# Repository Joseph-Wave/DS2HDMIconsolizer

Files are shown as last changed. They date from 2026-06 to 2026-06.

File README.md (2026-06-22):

## DS to HDMI converter

Here is an archive project of mine. It takes the raw video signals of the ds and scale up, pixel to pixel to DVI video in 1080p, 720p, etc. using an artix 7 FPGA (Cmod A7), and play both DS and GBA games.

Demotration can be seen at https://youtube.com/shorts/DusmrjSz5Js

Also share the PCB designs and pinout probing done in the ds family systems (LS030.xlsx), for which the DSi XL is electrically compatible and a second PCB and enclosure were desinged. 
The TFP410 TMDS transmitter and logic buffers are not required in most cases.

Some test roms are included. These are particulary coded to indentify the timing of the 5 bit RGB signals without expensive logic analizer, a cheap off-brand usb 8 Channels is enough.

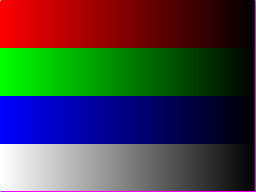
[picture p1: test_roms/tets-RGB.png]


The future plan was to pass the project to a Tang Primer 25K, a cheaper FPGA, or a dedicaded TFP410 Serializer. But never get the time and money to realize them. I share this in case someone had the same vision...
For more on the DVI serialization see: https://github.com/projf/display_controller

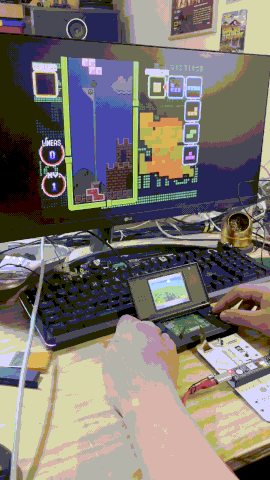
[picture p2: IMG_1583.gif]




The show scale correspont to a x5.

Here is a drawing of the expectated case using a DSi XL screen and a DS Fat motherboard (this model allow easier wiring as both screen data is recived for both displays, only with differing in the clock signal phase)

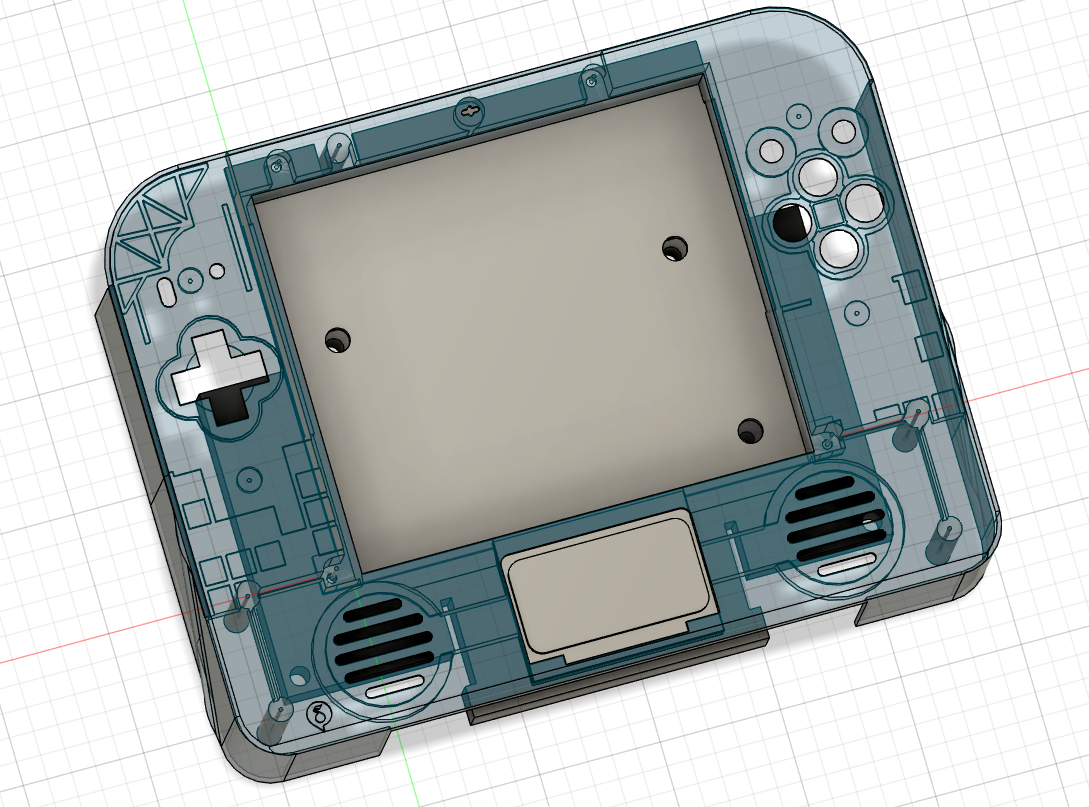
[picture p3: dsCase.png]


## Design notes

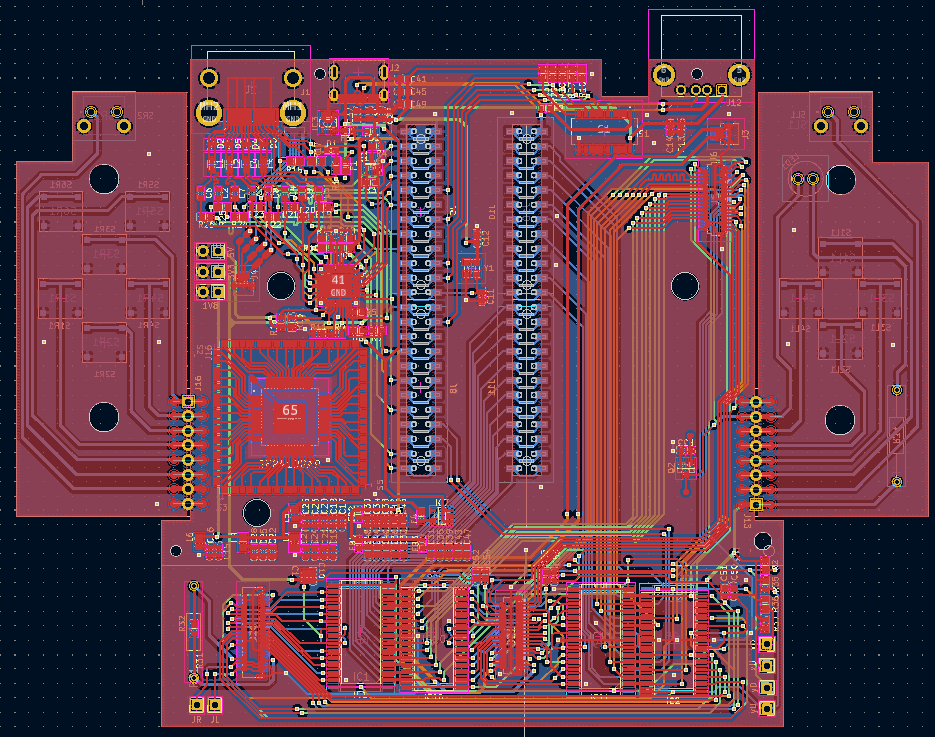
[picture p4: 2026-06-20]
pcb_v2.png

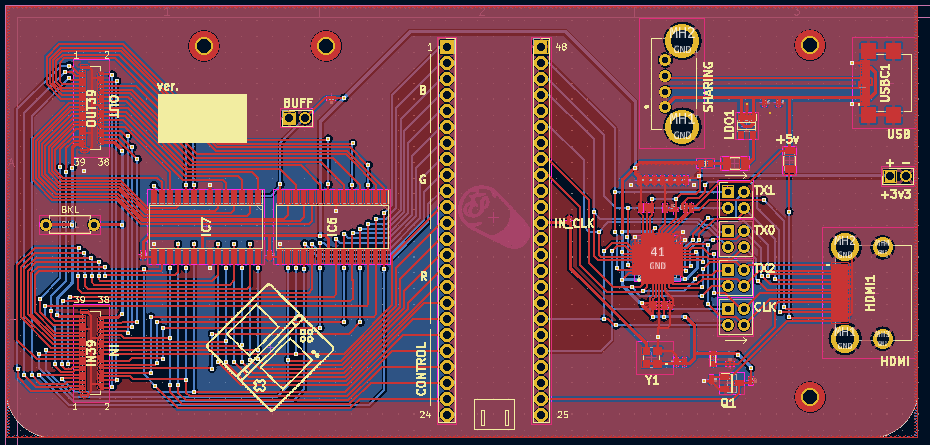
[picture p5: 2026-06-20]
pcb_v1.png

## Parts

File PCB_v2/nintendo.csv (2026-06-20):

Source: | C:\Users\Jojo\Documents\KiCad\nintendo\nintendo_v2b\nintendo\nintendo.kicad_sch
Date: | 9/28/2025 5:50:30 PM
Tool: | Eeschema 7.0.9
Generator: | C:\Program Files\KiCad\7.0\bin\scripting\plugins/bom_csv_grouped_by_value_with_fp.py
Component Count: | 170
Ref | Qnty | Value | Cmp name | Footprint | Description | Vendor | DNP
C1, C10, C16, C18, C20, C21, C23, C24, C25, C26, C27, C28, C34, C35, C36, C37, C38, C39, C40, C41, C42, C43, C44, C45, C46, C47, C48, C49, C50, C51, C52, C53, C54, C55 | 34 | 0.1uF | GRT188C81E475KE13D | Nintendo_Library:CAPC1608X100N | Multilayer Ceramic Capacitors MLCC - SMD/SMT 0603 25Vdc 4.7uF X6S 10%
C2, C3, C4, C5, C6, C7, C8, C9 | 8 | 100nF | GRT188C81E475KE13D | Nintendo_Library:CAPC1608X100N | Multilayer Ceramic Capacitors MLCC - SMD/SMT 0603 25Vdc 4.7uF X6S 10%
C11 | 1 | 0.01uF | GRT188C81E475KE13D | Nintendo_Library:CAPC1608X100N | Multilayer Ceramic Capacitors MLCC - SMD/SMT 0603 25Vdc 4.7uF X6S 10%
C12 | 1 | 15pF | GRT188C81E475KE13D | Nintendo_Library:CAPC1608X100N | Multilayer Ceramic Capacitors MLCC - SMD/SMT 0603 25Vdc 4.7uF X6S 10%
C13, C14, C15, C17, C19, C22, C29, C30, C31, C32, C33 | 11 | 10uF | GRT188C81E475KE13D | Nintendo_Library:CAPC1608X100N | Multilayer Ceramic Capacitors MLCC - SMD/SMT 0603 25Vdc 4.7uF X6S 10%
D1 | 1 | RB520S30T1G | RB520S30T1G | Nintendo_Library:SODFL1608X70N | These are Pb-Free Devices
D2, D3, D4, D5 | 4 | ESD122DMYR | ESD122DMYR | Nintendo_Library:ESD122DMYR | 2-Channel ESD Protection Diode for USB Type-C and HDMI 2.0
F1, F2, F3, F4 | 4 | 0467.250NR | 0467.250NR | Nintendo_Library:FUSC1608X43N | Littelfuse 0.25A FF Non-Resettable Surface Mount Fuses, 32 V
FB1, FB2, FB3, FB4 | 4 | BLM18RK601SN1D | BLM18RK601SN1D | Nintendo_Library:BLM18SP221SN1B | BLM18_N1D Series EMI Suppression Filter 600+/-25% at 100MHz 200mA @85
IC1, IC2, IC4, IC5, IC8, IC9, IC10, IC11 | 8 | SN74ABT5402ADWR | SN74ABT5402ADWR | Nintendo_Library:SOIC127P1030X265-28N | 12-Bit Line/Memory Drivers With 3-State Outputs
IC3 | 1 | BU33TD3WG-TR | BU33TD3WG-TR | Nintendo_Library:SOT95P280X125-5N | ROHM - BU33TD3WG-TR - LDO, FIXED, 3.3V, 0.2A, SSOP-5
IC6 | 1 | TMDS141RHAR | TMDS141RHAR | Nintendo_Library:QFN50P600X600X100-41N-D | HDMI Hider
IC7 | 1 | BU18TD3WG-TR | BU18TD3WG-TR | Nintendo_Library:SOT95P280X125-5N | 1ch 200mA CMOS LDO Regulators: The BU**TD2WNVX / BU**TD3WG series integrates a 200mA output high performance FULL CMOS regulator into an ultra-compact SSON004X1010 package (1.0mm1.0mm0.6mm) & SSOP5 package(2.9mm2.8mm1.15mm). Additional features include a circuit current of only 35A for low power consumption along with superior noise and load response characteristics, making them ideal for use in power supplies for a wide variety of applications, including logic ICs, RF circuits, and camera modules.
IC100 | 1 | TFP410PAP | TFP410PAP | Nintendo_Library:QFP50P1200X1200X120-65N | 165-MHz TMDS DVI transmitter/serializer & Panelbus integrated circuit
J1 | 1 | HDMI-208658-1051 | 208658-1051 | Nintendo_Library:2086581051 | 1.0 HDMI R/A HEADER ASSY (I/M TYPE)
J2 | 1 | USB4215-03-A_REVA | USB4215-03-A_REVA | Nintendo_Library:GCT_USB4215-03-A_REVA
J3, J4, J19 | 3 | 501461-0491 | 501461-0491 | Nintendo_Library:5014610491 | MOLEX - 501461-0491 - CONNECTOR, FPC, 4POS, 1ROW, 0.5MM
J5, J17, J18, J22, J23, J24 | 6 | 87224-1 | 87224-1 | Nintendo_Library:HDRV1W66P0X254_1X1 | 01 MODII HDR SRST UNSHRD .100
J6 | 1 | FH26W-37S-0.3SHW_60_ | FH26W-37S-0.3SHW_60_ | Nintendo_Library:FH26W37S03SHW60 | FFC & FPC Connectors Receptacle 37
J7, J14, J15 | 3 | 67996-100HLF | 67996-100HLF | Nintendo_Library:HDRV2W67P254_2X1_254X483X858P | BergStik<sup>&reg;</sup>, Board to Board connector, Unshrouded vertical header, Through Hole, Double Row, 0 Positions, 2.54 mm (0.100in) Pitch
J8, J9, J10, J11 | 4 | HLE-112-02-F-DV | HLE-112-02-F-DV | Nintendo_Library:HLE-112-02-XXX-DV | 24 Position, Cost Effective Surface Mount Socket, 0.100&quot; Pitch
J12 | 1 | USB1130-15-A | USB1130-15-A | Nintendo_Library:USB113015A | USB Connectors USB A 2.0 Skt RA High Life 15u" T Hole W/Shell Stake T & R
J13, J16 | 2 | ~ | th_separator | Nintendo_Library:th_separator
J20 | 1 | 502598-4593 | 502598-4593 | Nintendo_Library:5025984593 | Molex 502598 Series 0.3mm Pitch 45 Way SMT Female FPC Connector
J21 | 1 | 3-2328724-9 | 3-2328724-9 | Nintendo_Library:323287249 | AMP - TE CONNECTIVITY - 3-2328724-9 - CONNECTOR, FPC, R/A, 39POS, 1ROW, 0.3MM
L1, L2, L3, L4 | 4 | 744230900 | 744230900 | Nintendo_Library:744230900 | SMD Common Mode Noise Suppressor WE-CNSW
L5, L6, L7, L8 | 4 | 10uH | 74479777310 | Nintendo_Library:INDC2012X145N | Wurth WE-PMI Series 10000 nH +/-20% Multilayer SMD Inductor, 0805 Case, SRF: 0.025GHz 650mA dc 500m Rdc
LED1 | 1 | HLMP-K155 | HLMP-K155 | Nintendo_Library:HLMPK150C00A1 | 1.6 V Red LED 3mm Through Hole, Broadcom HLMP-K155
Q1, Q2 | 2 | FDV301N | FDV301N | Nintendo_Library:SOT96P237X111-3N | RDS(ON) = 5 @ VGS= 2.7 V; 25 V, 0.22 A continuous, 0.5 A Peak. ; RDS(ON) = 4 @ VGS= 4.5 VGS(th) < 1.06; Gate-Source Zener for ESD ruggedness. >6kV Human Body Model; Replace multiple NPN digital transistors with one DMOS FET
R1, R6, R7, R13, R15 | 5 | 1.5K | CR0603-FX-1002ELF | Nintendo_Library:RESC1608X55N | SMD 0603 thick film resistor 10K 1% Bourns CR0603-FX Series Thick Film Surface Mount Fixed Resistor 0603 Case 10k +/-1% 0.1W +/-100ppm/C
R2, R4, R8, R9, R10, R11, R12, R14, R16, R27, R28, R29, R30, R35, R36, R37 | 16 | 10K | CR0603-FX-1002ELF | Nintendo_Library:RESC1608X55N | SMD 0603 thick film resistor 10K 1% Bourns CR0603-FX Series Thick Film Surface Mount Fixed Resistor 0603 Case 10k +/-1% 0.1W +/-100ppm/C
R3, R33 | 2 | 100K | CR0603-FX-1002ELF | Nintendo_Library:RESC1608X55N | SMD 0603 thick film resistor 10K 1% Bourns CR0603-FX Series Thick Film Surface Mount Fixed Resistor 0603 Case 10k +/-1% 0.1W +/-100ppm/C
R5 | 1 | 4.6K | CR0603-FX-1002ELF | Nintendo_Library:RESC1608X55N | SMD 0603 thick film resistor 10K 1% Bourns CR0603-FX Series Thick Film Surface Mount Fixed Resistor 0603 Case 10k +/-1% 0.1W +/-100ppm/C
R17, R18, R19, R20, R21, R22, R23, R24, R25, R26 | 10 | 0 | CR0603-FX-1002ELF | Nintendo_Library:RESC1608X55N | SMD 0603 thick film resistor 10K 1% Bourns CR0603-FX Series Thick Film Surface Mount Fixed Resistor 0603 Case 10k +/-1% 0.1W +/-100ppm/C
R31, R34 | 2 | 330 | MFR-25FRF52-10K | Nintendo_Library:RESAD1590W60L630D240 | Metal Film Resistors - Through Hole 10 kOhms 250 mW 1% 100 PPM / C
R32 | 1 | 330 | CR0603-FX-1002ELF | Nintendo_Library:RESC1608X55N | SMD 0603 thick film resistor 10K 1% Bourns CR0603-FX Series Thick Film Surface Mount Fixed Resistor 0603 Case 10k +/-1% 0.1W +/-100ppm/C
S1 | 1 | A6H-8102-PM | A6H-8102-PM | Nintendo_Library:A6H8102PM | DIP Switches / SIP Switches REFLOW TERMINAL DIP
S1L1 | 1 | SKRRAAE010 | SKRRAAE010 | Nintendo_Library:SKRR | Tactile Switches 7.5x7.0x0.6mm 100gf
S1R1 | 1 | SKRRAAE010 | SKRRAAE010 | Nintendo_Library:SKRR | Tactile Switches 7.5x7.0x0.6mm 100gf
S2, S3, S4, S5 | 4 | ~ | Easy_Solder | Nintendo_Library:Easy_Solder
S2L1 | 1 | SKRRAAE010 | SKRRAAE010 | Nintendo_Library:SKRR | Tactile Switches 7.5x7.0x0.6mm 100gf
S2R1 | 1 | SKRRAAE010 | SKRRAAE010 | Nintendo_Library:SKRR | Tactile Switches 7.5x7.0x0.6mm 100gf
S3L1 | 1 | SKRRAAE010 | SKRRAAE010 | Nintendo_Library:SKRR | Tactile Switches 7.5x7.0x0.6mm 100gf
S3R1 | 1 | SKRRAAE010 | SKRRAAE010 | Nintendo_Library:SKRR | Tactile Switches 7.5x7.0x0.6mm 100gf
S4L1 | 1 | SKRRAAE010 | SKRRAAE010 | Nintendo_Library:SKRR | Tactile Switches 7.5x7.0x0.6mm 100gf
S4R1 | 1 | SKRRAAE010 | SKRRAAE010 | Nintendo_Library:SKRR | Tactile Switches 7.5x7.0x0.6mm 100gf
S5R1 | 1 | SKRRAAE010 | SKRRAAE010 | Nintendo_Library:SKRR | Tactile Switches 7.5x7.0x0.6mm 100gf
S6R1 | 1 | SKRRAAE010 | SKRRAAE010 | Nintendo_Library:SKRR | Tactile Switches 7.5x7.0x0.6mm 100gf
SL1 | 1 | 1-1825027-2 | 1-1825027-2 | 118250272 | Switch Tactile OFF (ON) SPST Round Button PC Pins 0.05A 24VDC 2.55N Thru-Hole Loose
SR2 | 1 | 1-1825027-2 | 1-1825027-2 | 118250272 | Switch Tactile OFF (ON) SPST Round Button PC Pins 0.05A 24VDC 2.55N Thru-Hole Loose
Y1 | 1 | DSC1001CE5-148.5000T | DSC1001CE5-148.5000T | Nintendo_Library:DSC1001CE5-148.5000T | 1.8V-3.3V Low-Power Precision CMOS Oscillators

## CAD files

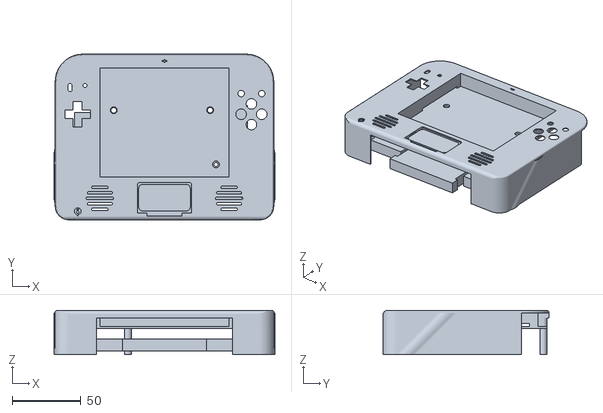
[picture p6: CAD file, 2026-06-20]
dsCase.stl
160.6 x 120.4 x 32.0

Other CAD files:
dsCase.f3d

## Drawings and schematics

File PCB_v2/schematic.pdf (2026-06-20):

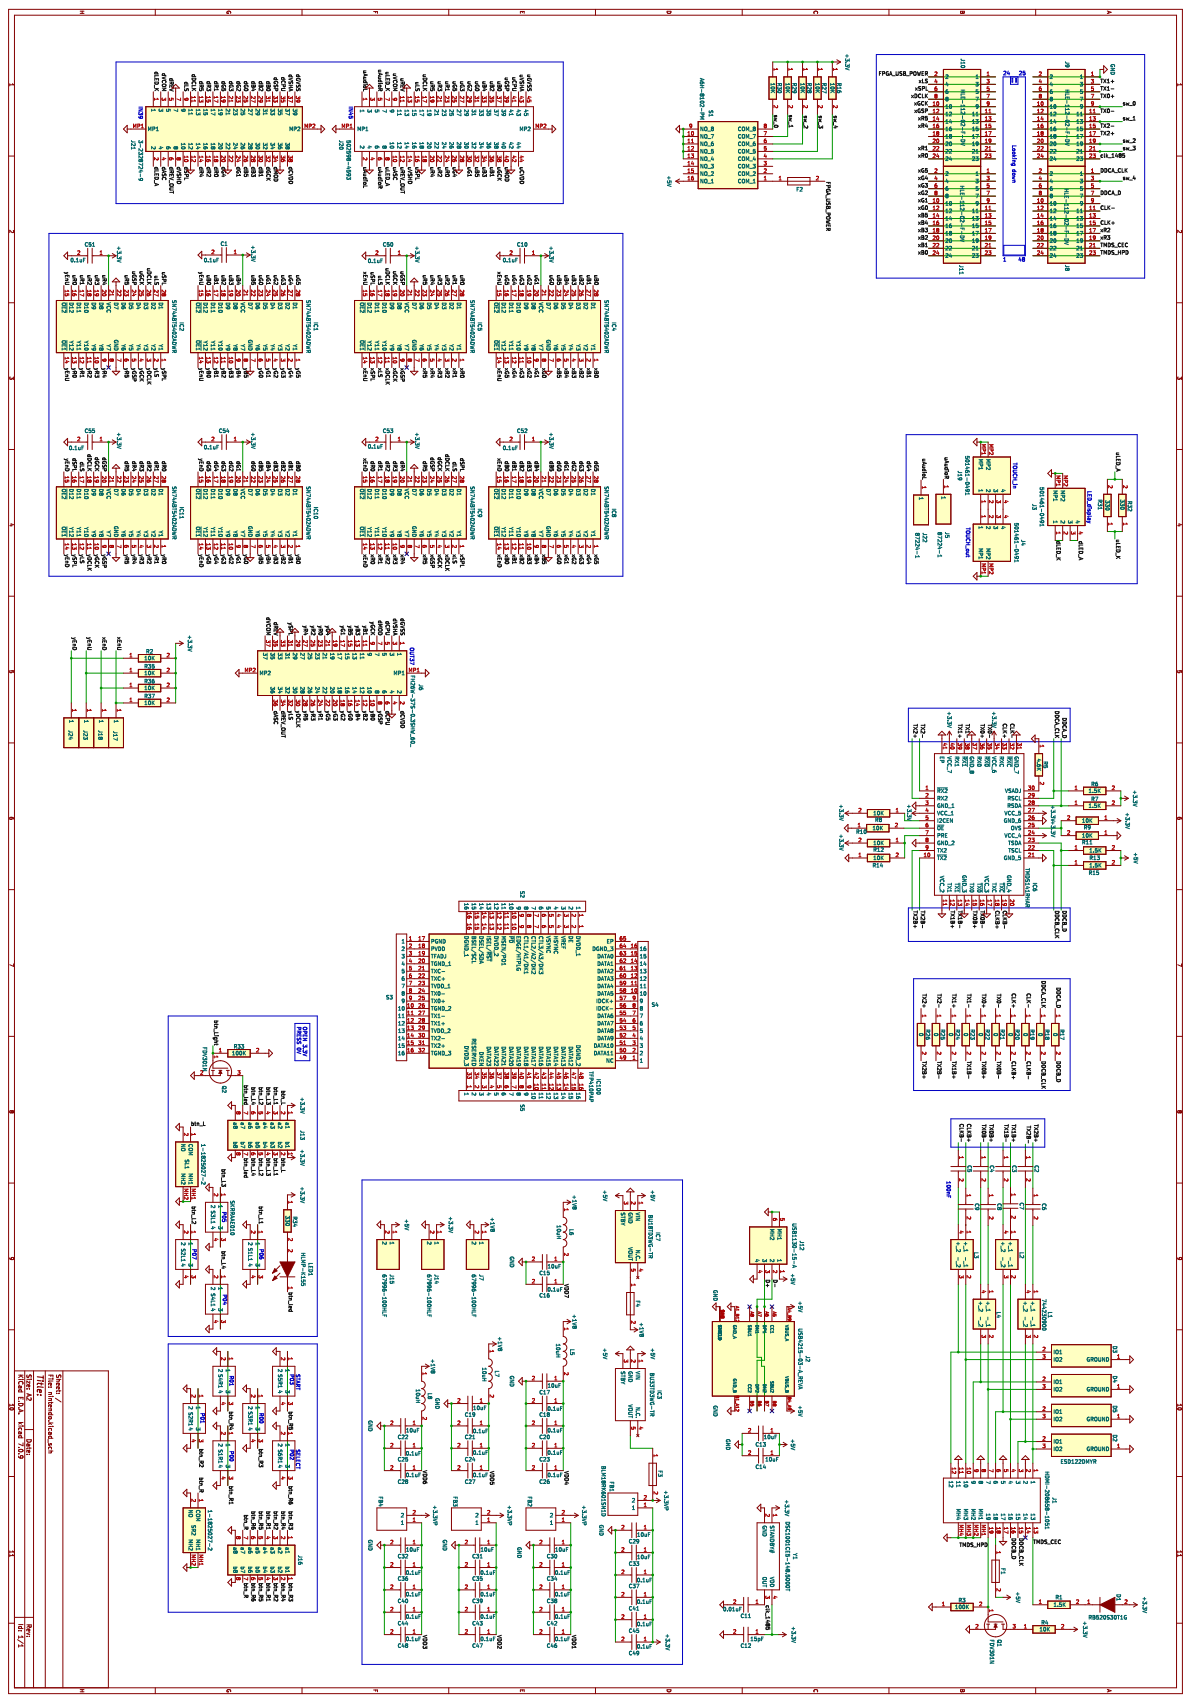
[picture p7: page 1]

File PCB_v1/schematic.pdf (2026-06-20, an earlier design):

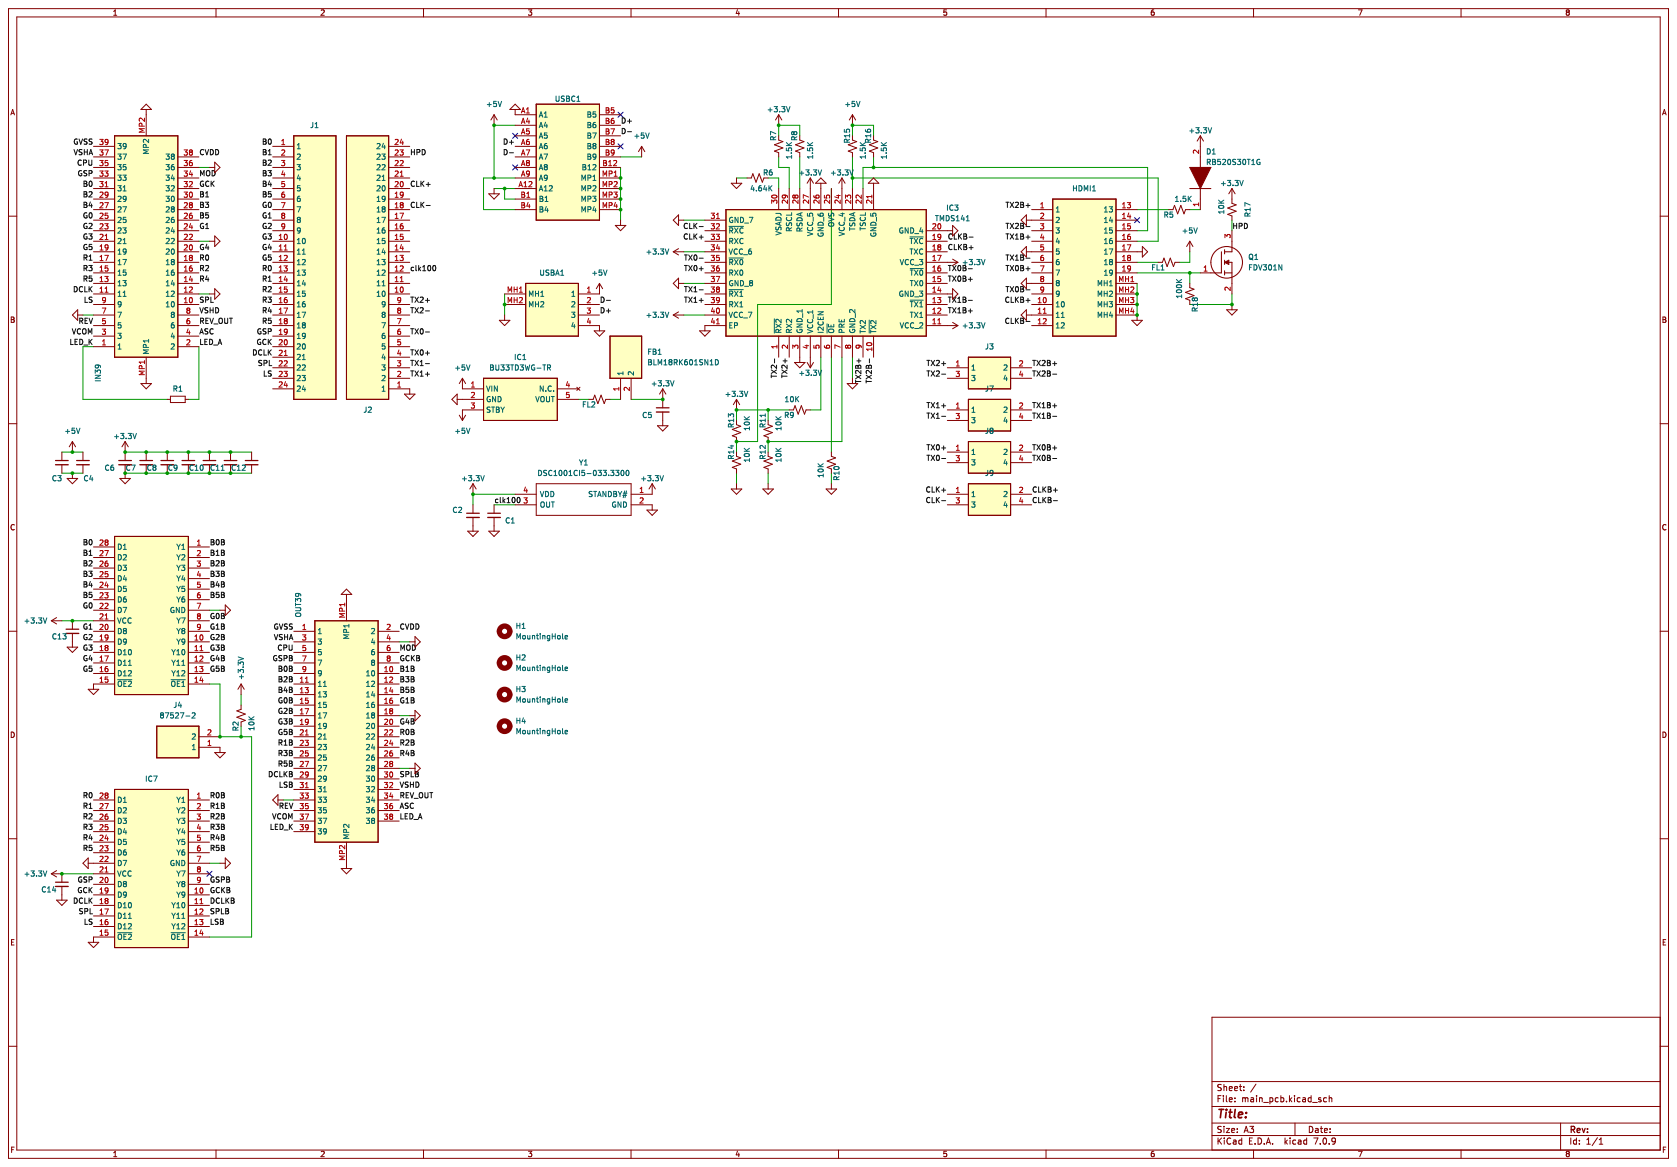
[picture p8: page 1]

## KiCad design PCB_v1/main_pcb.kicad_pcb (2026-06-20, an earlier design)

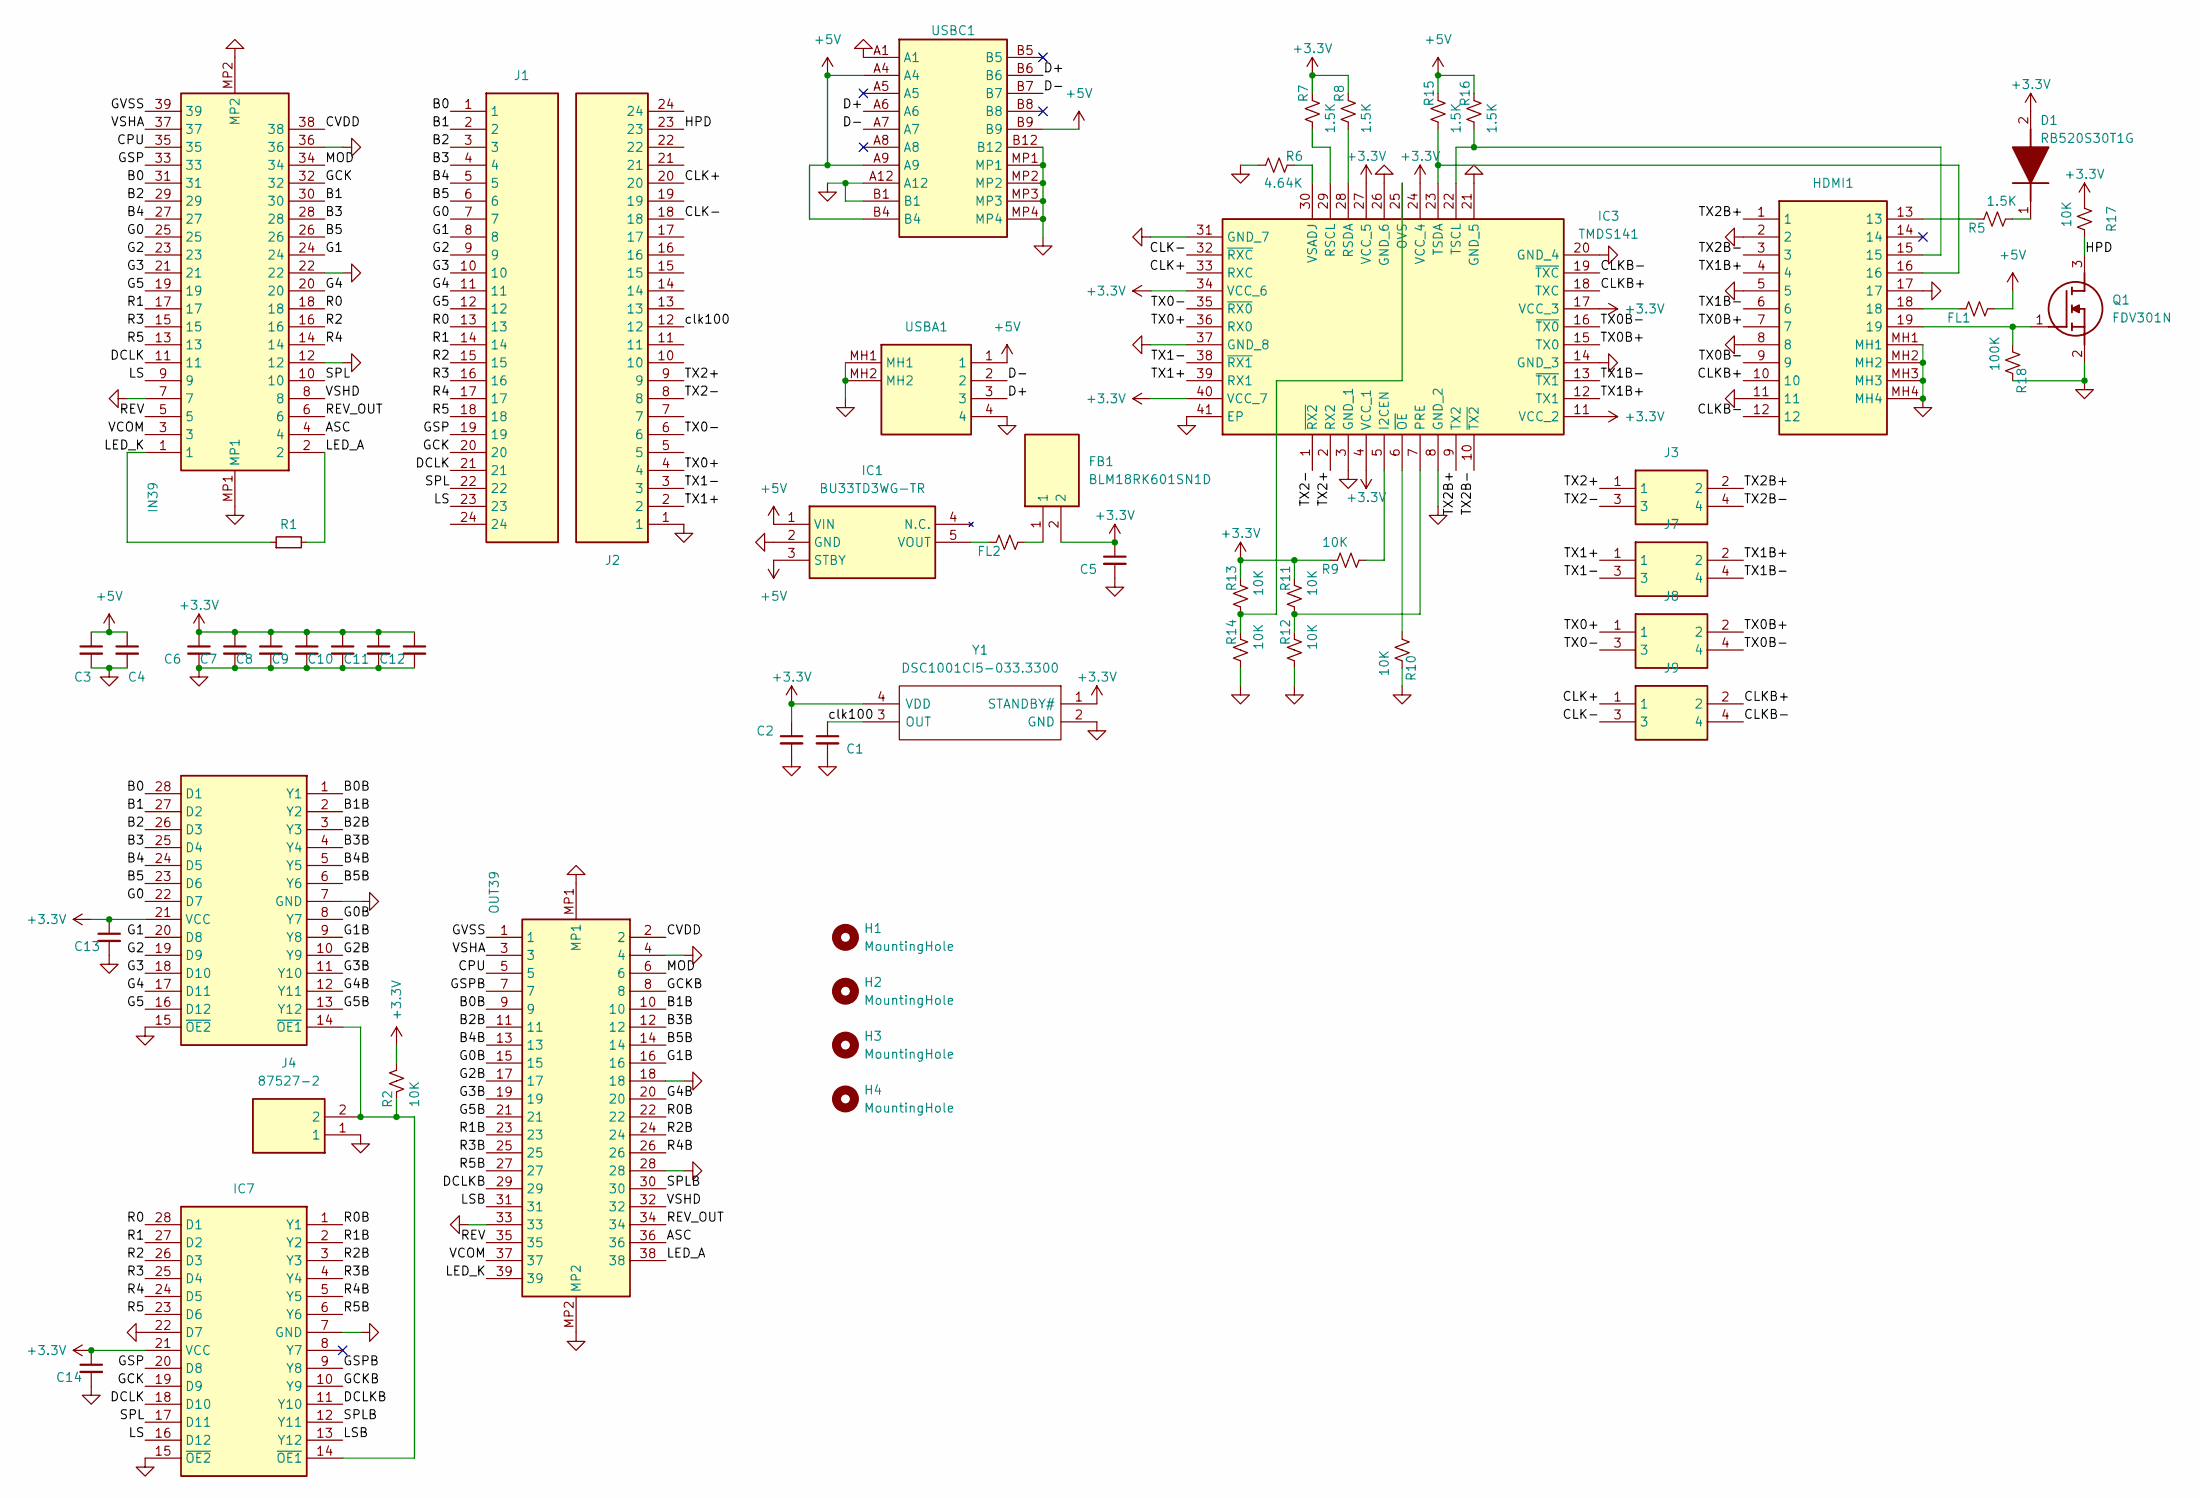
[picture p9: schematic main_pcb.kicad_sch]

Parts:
C1, C2, C3, C4, C5, C6, C7, C8, C9, C10, C11, C12, C13, C14: C_Small; C_0201_0603Metric
D1: RB520S30T1G; SODFL1608X70N; Mouser Part Number 863-RB520S30T1G
FB1: BLM18RK601SN1D; BLM18SP221SN1B; Mouser Part Number 81-BLM18RK601SN1
FL1, FL2: 10K; R_1206_3216Metric
H1, H2, H3, H4: MountingHole; MountingHole_2.2mm_M2_Pad_TopBottom
HDMI1: 208658-1051; 2086581051; Mouser Part Number 538-208658-1051
IC1: BU33TD3WG-TR; SOT95P280X125-5N; Mouser Part Number 755-BU33TD3WG-TR
IC3: TMDS141; QFN50P600X600X100-41N-D; Mouser Part Number 595-TMDS141RHAR
IC6, IC7: SN74ABT5402ADWR; SOIC127P1030X265-28N; Mouser Part Number 595-SN74ABT5402ADWR
IN39: 3-2328724-9; 323287249; Mouser Part Number 571-3-2328724-9
J1, J2: 929850-01-24-RA; RHDR24W76P0X254_1X24_6096X254X826P; Mouser Part Number 517-929850-01-24-RA
J3, J7, J8, J9: 826632-2; HDRV4W85P254_2X2_508X500X970P; Mouser Part Number 571-826632-2
J4: 87527-2; HDRV2W66P0X254_1X2_467X244X1044P; Mouser Part Number 571-875272
OUT39: 3-2328724-9; 323287249; Mouser Part Number 571-3-2328724-9
Q1: FDV301N; SOT96P237X111-3N; Mouser Part Number 512-FDV301N
R1: R_Small; R_Axial_DIN0207_L6.3mm_D2.5mm_P7.62mm_Horizontal
R2, R9, R10, R11, R12, R13, R14, R17: 10K; R_0201_0603Metric
R5, R7, R8, R15, R16: 1.5K; R_0201_0603Metric
R6: 4.64K; R_0201_0603Metric
R18: 100K; R_0201_0603Metric
USBA1: 1734366-2; 17343662; Mouser Part Number 571-1734366-2
USBC1: USB4110-GF-A; USB4110GFA; Mouser Part Number 640-USB4110-GF-A
Y1: DSC1001CI5-033.3300; DSC1001CI50333300; Mouser Part Number 579-SC1001CI50333300

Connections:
+5V: C3.1, C4.1, FL1.1, IC1.1 (VIN), IC1.3 (STBY), R15.2, R16.2, USBA1.1, USBC1.A4, USBC1.A9, USBC1.B4, USBC1.B9
/ASC: IN39.4, OUT39.36
/B0: IC6.28 (D1), IN39.31, J1.1
/B0B: IC6.1 (Y1), OUT39.9
/B1: IC6.27 (D2), IN39.30, J1.2
/B1B: IC6.2 (Y2), OUT39.10
/B2: IC6.26 (D3), IN39.29, J1.3
/B2B: IC6.3 (Y3), OUT39.11
/B3: IC6.25 (D4), IN39.28, J1.4
/B3B: IC6.4 (Y4), OUT39.12
/B4: IC6.24 (D5), IN39.27, J1.5
/B4B: IC6.5 (Y5), OUT39.13
/B5: IC6.23 (D6), IN39.26, J1.6
/B5B: IC6.6 (Y6), OUT39.14
/CLK+: IC3.33 (RXC), J2.20, J9.1
/CLK-: IC3.32 (~RXC), J2.18, J9.3
/CLKB+: HDMI1.10, IC3.18 (TXC), J9.2
/CLKB-: HDMI1.12, IC3.19 (~TXC), J9.4
/CPU: IN39.35, OUT39.5
/CVDD: IN39.38, OUT39.2
/D+: USBA1.3, USBC1.A6, USBC1.B6
/D-: USBA1.2, USBC1.A7, USBC1.B7
/DCLK: IC7.18 (D10), IN39.11, J1.21
/DCLKB: IC7.11 (Y10), OUT39.29
/G0: IC6.22 (D7), IN39.25, J1.7
/G0B: IC6.8 (Y7), OUT39.15
/G1: IC6.20 (D8), IN39.24, J1.8
/G1B: IC6.9 (Y8), OUT39.16
/G2: IC6.19 (D9), IN39.23, J1.9
/G2B: IC6.10 (Y9), OUT39.17
/G3: IC6.18 (D10), IN39.21, J1.10
/G3B: IC6.11 (Y10), OUT39.19
/G4: IC6.17 (D11), IN39.20, J1.11
/G4B: IC6.12 (Y11), OUT39.20
/G5: IC6.16 (D12), IN39.19, J1.12
/G5B: IC6.13 (Y12), OUT39.21
/GCK: IC7.19 (D9), IN39.32, J1.20
/GCKB: IC7.10 (Y9), OUT39.8
/GSP: IC7.20 (D8), IN39.33, J1.19
/GSPB: IC7.9 (Y8), OUT39.7
/GVSS: IN39.39, OUT39.1
/HPD: J2.23, Q1.3 (D), R17.2
/LED_A: IN39.2, OUT39.38, R1.2; also elsewhere on the board
/LED_K: IN39.1, OUT39.39, R1.1; also elsewhere on the board
/LS: IC7.16 (D12), IN39.9, J1.23
/LSB: IC7.13 (Y12), OUT39.31
/MOD: IN39.34, OUT39.6
/R0: IC7.28 (D1), IN39.18, J1.13
/R0B: IC7.1 (Y1), OUT39.22
/R1: IC7.27 (D2), IN39.17, J1.14
/R1B: IC7.2 (Y2), OUT39.23
/R2: IC7.26 (D3), IN39.16, J1.15
/R2B: IC7.3 (Y3), OUT39.24
/R3: IC7.25 (D4), IN39.15, J1.16
/R3B: IC7.4 (Y4), OUT39.25
/R4: IC7.24 (D5), IN39.14, J1.17
/R4B: IC7.5 (Y5), OUT39.26
/R5: IC7.23 (D6), IN39.13, J1.18
/R5B: IC7.6 (Y6), OUT39.27
/REV: IN39.5, OUT39.35
/REV_OUT: IN39.6, OUT39.34
/SPL: IC7.17 (D11), IN39.10, J1.22
/SPLB: IC7.12 (Y11), OUT39.30
/TX0+: IC3.36 (RX0), J2.4, J8.1
/TX0-: IC3.35 (~RX0), J2.6, J8.3
/TX0B+: HDMI1.7, IC3.15 (TX0), J8.2
/TX0B-: HDMI1.9, IC3.16 (~TX0), J8.4
/TX1+: IC3.39 (RX1), J2.2, J7.1
/TX1-: IC3.38 (~RX1), J2.3, J7.3
/TX1B+: HDMI1.4, IC3.12 (TX1), J7.2
/TX1B-: HDMI1.6, IC3.13 (~TX1), J7.4
/TX2+: IC3.2 (RX2), J2.9, J3.1
/TX2-: IC3.1 (~RX2), J2.8, J3.3
/TX2B+: HDMI1.1, IC3.9 (TX2), J3.2
/TX2B-: HDMI1.3, IC3.10 (~TX2), J3.4
/VCOM: IN39.3, OUT39.37
/VSHA: IN39.37, OUT39.3
/VSHD: IN39.8, OUT39.32
/clk100: C1.1, J2.12, Y1.3 (OUT)
unnamed: D1.1 (K), R5.1
unnamed: FB1.1, FL2.1
unnamed: FL1.2, HDMI1.18
unnamed: HDMI1.13, R5.2
unnamed: FL2.2, IC1.5 (VOUT)
unnamed: IC3.5 (I2CEN), R9.1
unnamed: IC3.25 (OVS), R13.1, R14.2
unnamed: IC3.7 (PRE), R11.1, R12.2
unnamed: IC3.29 (RSCL), R7.1
unnamed: IC3.28 (RSDA), R8.1
unnamed: HDMI1.15, IC3.22 (TSCL), R16.1
unnamed: HDMI1.16, IC3.23 (TSDA), R15.1
unnamed: IC3.30 (VSADJ), R6.2
unnamed: IC3.6 (~OE), R10.1
unnamed: HDMI1.19, Q1.1 (G), R18.1

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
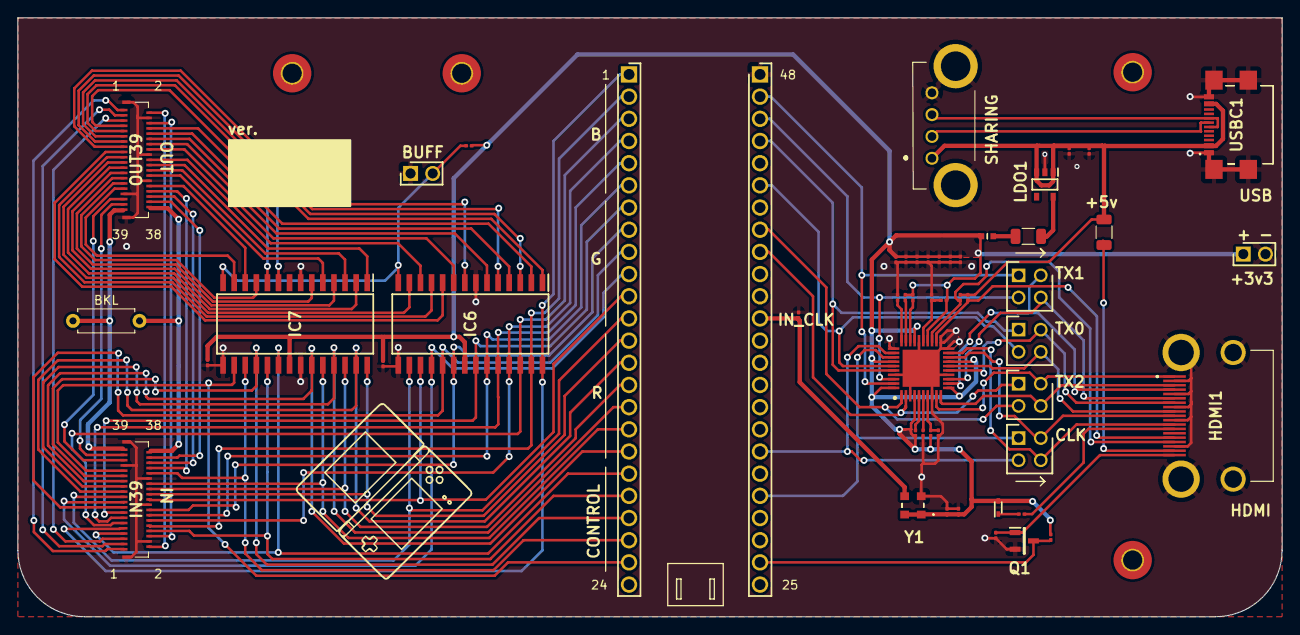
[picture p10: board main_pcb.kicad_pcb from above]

Board: 2 copper layers, 144.8 x 68.6 mm, 57 parts (0 on the bottom side), 97 nets.

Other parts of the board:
BKL: R_Small; R_Axial_DIN0207_L6.3mm_D2.5mm_P7.62mm_Horizontal
J4#2: 87527-2; HDRV2W66P0X254_1X2_467X244X1044P

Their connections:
/LED_A: BKL.2; also elsewhere on the board
/LED_K: BKL.1; also elsewhere on the board

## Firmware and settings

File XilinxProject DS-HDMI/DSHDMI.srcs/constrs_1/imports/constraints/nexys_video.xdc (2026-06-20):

# WNS	TNS
# -3.3	-216.8	mix pin
# -3.1	-184.1	row pin + 2 pin in block 34, FINAL
# -3.2	-229.5	new, Looks like distribute all pins in minimal/same blocks saturate the blocks, 
#				but I cannot find the optimal point without checking every config, need to reed more documentation

## FPGA Configuration I/O Options
set_property CONFIG_VOLTAGE 3.3 [current_design];
set_property CFGBVS VCCO [current_design];

## Master Clock: 12 MHz
set_property -dict {PACKAGE_PIN L17 IOSTANDARD LVCMOS33} [get_ports clk];
create_clock -period 83.333 -name clk_12m [get_ports clk];

## Master Clock: 100 MHz
#set_property -dict {PACKAGE_PIN W5 IOSTANDARD LVCMOS33} [get_ports clk]; #PIO36
#create_clock -period 10.000 -name clk_100m -add [get_ports clk];
#set_input_delay -clock clk_100m 1 [all_inputs]

## HDMI Output (Source)
#set_property -dict {PACKAGE_PIN U8 IOSTANDARD LVCMOS33} [get_ports hdmi_tx_cec]; #IO_L14P_T2_SRCC_34 Sch=pio[47]				BANK 34
#set_property -dict {PACKAGE_PIN V8 IOSTANDARD LVCMOS33} [get_ports hdmi_tx_hpd]; #IO_L14N_T2_SRCC_34 Sch=pio[48]				BANK 34
#set_property -dict {PACKAGE_PIN U4	IOSTANDARD LVCMOS33 } [get_ports hdmi_tx_hpd]; #IO_L11P_T1_SRCC_34 Sch=pio[38]				BANK 34
#set_property -dict {PACKAGE_PIN V4 IOSTANDARD LVCMOS33} [get_ports hdmi_tx_rscl]; #IO_L11N_T1_SRCC_34 Sch=pio[37]				BANK 34
#set_property -dict {PACKAGE_PIN W4 IOSTANDARD LVCMOS33} [get_ports hdmi_tx_rsda]; #IO_L12N_T1_MRCC_34 Sch=pio[40]				BANK 34
set_property -dict {PACKAGE_PIN U2   IOSTANDARD TMDS_33 } [get_ports {hdmi_tx_clk_n}]; #IO_L9N_T1_DQS_34 Sch=pio[42]			BANK 34
set_property -dict {PACKAGE_PIN U3   IOSTANDARD TMDS_33 } [get_ports {hdmi_tx_clk_p}]; #IO_L9P_T1_DQS_34 Sch=pio[44]			BANK 34
set_property -dict {PACKAGE_PIN T2   IOSTANDARD TMDS_33 } [get_ports {hdmi_tx_n[0] }]; #IO_L1N_T0_34 Sch=pio[30]				BANK 34
set_property -dict {PACKAGE_PIN R2   IOSTANDARD TMDS_33 } [get_ports {hdmi_tx_p[0] }]; #IO_L1P_T0_34 Sch=pio[28]				BANK 34
set_property -dict {PACKAGE_PIN T3   IOSTANDARD TMDS_33 } [get_ports {hdmi_tx_n[1] }]; #IO_L2N_T0_34 Sch=pio[27]				BANK 34
set_property -dict {PACKAGE_PIN R3   IOSTANDARD TMDS_33 } [get_ports {hdmi_tx_p[1] }]; #IO_L2P_T0_34 Sch=pio[26]				BANK 34
set_property -dict {PACKAGE_PIN W2   IOSTANDARD TMDS_33 } [get_ports {hdmi_tx_n[2] }]; #IO_L5N_T0_34 Sch=pio[32]				BANK 34
set_property -dict {PACKAGE_PIN V2   IOSTANDARD TMDS_33 } [get_ports {hdmi_tx_p[2] }]; #IO_L5P_T0_34 Sch=pio[33]				BANK 34

## GPIO Pins
# ['GSP' 'GCK' 'DCLK' 'SPL' 'LS'] -> [4:0]

set_property -dict { PACKAGE_PIN P1    IOSTANDARD LVCMOS33 } [get_ports { pin_control[0] }]; #IO_L19N_T3_VREF_35 Sch=pio[23]	BANK 35
set_property -dict { PACKAGE_PIN N2    IOSTANDARD LVCMOS33 } [get_ports { pin_control[1] }]; #IO_L10P_T1_AD15P_35 Sch=pio[22]	BANK 35
set_property -dict { PACKAGE_PIN N1    IOSTANDARD LVCMOS33 } [get_ports { pin_control[2] }]; #IO_L10N_T1_AD15N_35 Sch=pio[21]	BANK 35
set_property -dict { PACKAGE_PIN M2    IOSTANDARD LVCMOS33 } [get_ports { pin_control[3] }]; #IO_L9P_T1_DQS_AD7P_35 Sch=pio[20]	BANK 35
set_property -dict { PACKAGE_PIN P3    IOSTANDARD LVCMOS33 } [get_ports { pin_control[4] }]; #IO_L12N_T1_MRCC_35 Sch=pio[19]	BANK 35

# blue = pin_RGB[5:0], green = pin_RGB[11:6], red = pin_RGB[17:12], Alphas pins: 0, 6, 12
# Blue
set_property -dict { PACKAGE_PIN M3    IOSTANDARD LVCMOS33 } [get_ports { pin_RGB[0] }]; #IO_L8N_T1_AD14N_35 Sch=pio[01]		BANK 35
set_property -dict { PACKAGE_PIN L3    IOSTANDARD LVCMOS33 } [get_ports { pin_RGB[1] }]; #IO_L8P_T1_AD14P_35 Sch=pio[02]		BANK 35
set_property -dict { PACKAGE_PIN A16   IOSTANDARD LVCMOS33 } [get_ports { pin_RGB[2] }]; #IO_L12P_T1_MRCC_16 Sch=pio[03]		BANK 16
set_property -dict { PACKAGE_PIN K3    IOSTANDARD LVCMOS33 } [get_ports { pin_RGB[3] }]; #IO_L7N_T1_AD6N_35 Sch=pio[04]			BANK 35
set_property -dict { PACKAGE_PIN C15   IOSTANDARD LVCMOS33 } [get_ports { pin_RGB[4] }]; #IO_L11P_T1_SRCC_16 Sch=pio[05]		BANK 16
set_property -dict { PACKAGE_PIN H1    IOSTANDARD LVCMOS33 } [get_ports { pin_RGB[5] }]; #IO_L3P_T0_DQS_AD5P_35 Sch=pio[06]		BANK 35
# Green
set_property -dict { PACKAGE_PIN A15   IOSTANDARD LVCMOS33 } [get_ports { pin_RGB[6] }]; #IO_L6N_T0_VREF_16 Sch=pio[07]			BANK 16
set_property -dict { PACKAGE_PIN B15   IOSTANDARD LVCMOS33 } [get_ports { pin_RGB[7] }]; #IO_L11N_T1_SRCC_16 Sch=pio[08]		BANK 16
set_property -dict { PACKAGE_PIN A14   IOSTANDARD LVCMOS33 } [get_ports { pin_RGB[8] }]; #IO_L6P_T0_16 Sch=pio[09]				BANK 16
set_property -dict { PACKAGE_PIN J3    IOSTANDARD LVCMOS33 } [get_ports { pin_RGB[9] }]; #IO_L7P_T1_AD6P_35 Sch=pio[10]			BANK 35
set_property -dict { PACKAGE_PIN J1    IOSTANDARD LVCMOS33 } [get_ports { pin_RGB[10] }]; #IO_L3N_T0_DQS_AD5N_35 Sch=pio[11]	BANK 35
set_property -dict { PACKAGE_PIN K2    IOSTANDARD LVCMOS33 } [get_ports { pin_RGB[11] }]; #IO_L5P_T0_AD13P_35 Sch=pio[12]		BANK 35
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
